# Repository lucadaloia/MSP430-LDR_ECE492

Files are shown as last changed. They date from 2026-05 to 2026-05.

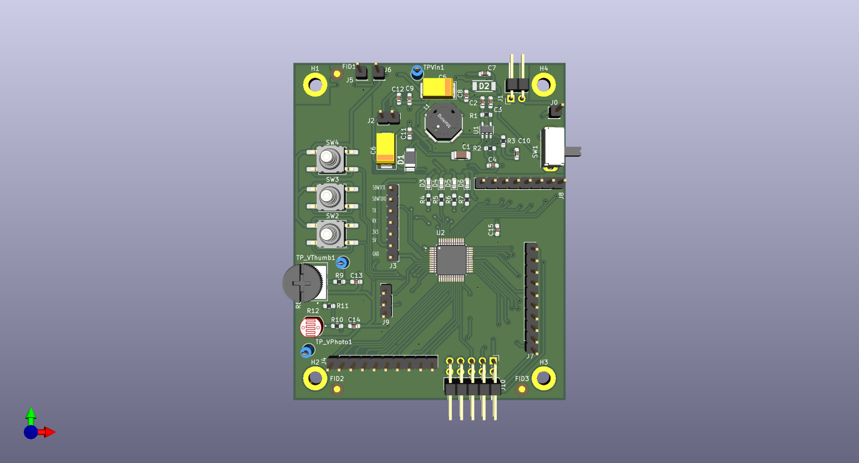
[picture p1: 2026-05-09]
Design Documents/ECE 492 - PCB 3D Render.png

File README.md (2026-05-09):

# MSP430-LDR_ECE492 
### ECE 492 (Embedded Systems Hardware Design) Project

## 📝 Overview
This project involved the design and manufacturing of a microcontroller-based system focused on analog signal acquisition and real-time user interaction. The system utilizes a photoresistor (LDR) for environmental sensing and a tactile user interface, all managed by a custom-designed PCB and optimized C firmware.

The core of the system is the **MSP430FR2355**, utilizing its 10-bit ADC12 module and hardware timers to create a responsive, low-power monitoring tool.

## 🛠 Hardware Specifications
- **MCU:** MSP430
- **Sensors:** Photoresistor (Analog A1) & Thumbwheel Potentiometer (Analog A2)
- **User Input:** 3x Tactile Pushbuttons (Hardware Interrupts)
- **Visual Output:** 4x LED Status Indicators (Blue, Yellow, Green, Red)

## 📂 Project Structure
- `main.c`: Central application logic and LED threshold management.
- `ADC.c`: 10-bit ADC12 configuration and sampling logic.
- `interrupts.c`: ISRs for Port 2 (Mode switching), Timer B (10Hz trigger), and ADC.
- `ports.c`: GPIO and Peripheral multiplexing setup.
- `timers.c`: Timer_B0 configuration using ACLK (~32.768 kHz).
- `globals.c`: Volatile variable definitions for shared system state.

## ⚙️ Technical Highlights
### 1. Automated ADC Chaining
To minimize CPU overhead, the firmware uses a "chaining" logic within the ADC Interrupt Service Routine. Once the photoresistor is sampled, the ISR automatically reconfigures the multiplexer to sample the thumbwheel, ensuring all sensor data is current without blocking the main loop.

### 2. Interrupt-Driven State Machine
The system switches between three operating modes via Port 2 interrupts:
- **Mode 1:** All-or-nothing binary threshold.
- **Mode 2:** Graduated response (LEDs light up sequentially based on intensity).
- **Mode 3:** Environmental calibration and baseline setting.

---
**Author:** Luca Daloia  
**Project Date:** Spring 2026  
**Course:** ECE 492

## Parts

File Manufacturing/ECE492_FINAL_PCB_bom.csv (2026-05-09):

Designator | Footprint | Quantity | Value | LCSC Part #
C1 | 1206 | 1 | 1.0UF
C10, C11, C12, C16, C17, C18, C19, C2, C20, C21, C22, C23, C24, C25, C7, C8, C9 | 0603 | 17 | 10UF
C13, C14, C15 | 0603 | 3 | 0.1uF
C3, C4 | 0603 | 2 | 470PF
C5 | CP_EIA-7132-20_AVX-U | 1 | 22UF
C6 | CP_EIA-7343-40_Kemet-Y | 1 | 100UF
D1, D2 | PMEG3020BEP,115 | 2 | PMEG3020BEP,115
D3 | 0603 | 1 | LTST-C190GKT
D4 | 0603 | 1 | LTST-C190KRKT
D5 | 0603 | 1 | LTST-C190KSKT
D6 | 0603 | 1 | LTST-C190TBKT
J0, J5, J6 | PinHeader_1x01_P2.54mm_Vertical | 3 | Conn_01x01
J1 | PinHeader_1x02_P2.54mm_Horizontal | 1 | Conn_01x02
J10 | PinHeader_2x05_P2.54mm_Horizontal | 1 | Conn_02x05_Odd_Even
J2 | PinHeader_1x02_P2.54mm_Vertical | 1 | Conn_01x02
J3 | PinHeader_1x07_P2.54mm_Vertical | 1 | Conn_01x07_Pin
J4, J7 | PinHeader_1x10_P2.54mm_Vertical | 2 | Conn_01x10_Pin
J8 | PinHeader_1x08_P2.54mm_Vertical | 1 | Conn_01x08_Pin
J9 | PinHeader_1x03_P2.54mm_Vertical | 1 | Conn_01x05_Pin
L1 | WE-TDC_8038 | 1 | WE-TDC_8038
R1 | 0603 | 1 | 10.0K
R10, R9 | 0603 | 2 | 1k
R11 | 0603 | 1 | 10k
R12 | PHODET_PDV-P8103 | 1 | PDV-P8103
R2 | 0603 | 1 | 12K
R3 | 0603 | 1 | 20K
R4, R5, R6, R7 | 0603 | 4 | 220
R8 | TRIM_3352T-1-103LF | 1 | 3352T-1-103LF
SW1 | SW_Slide_SPDT_Angled_CK_OS102011MA1Q | 1 | SW_SPDT
SW2, SW3, SW4 | SW_Push_1P1T_NO_CK_KSC9xxG | 3 | SW_DIP_x01
TPVIN1, TP_VPHOTO1, TP_VTHUMB1 | TestPoint_Loop_D1.80mm_Drill1.0mm_Beaded | 3 | TestPoint
U1 | LT1935ES5-TRPBF | 1 | LT1935ES5-TRPBF
U2 | MSP430FR2355TPT | 1 | MSP430FR2355TPT

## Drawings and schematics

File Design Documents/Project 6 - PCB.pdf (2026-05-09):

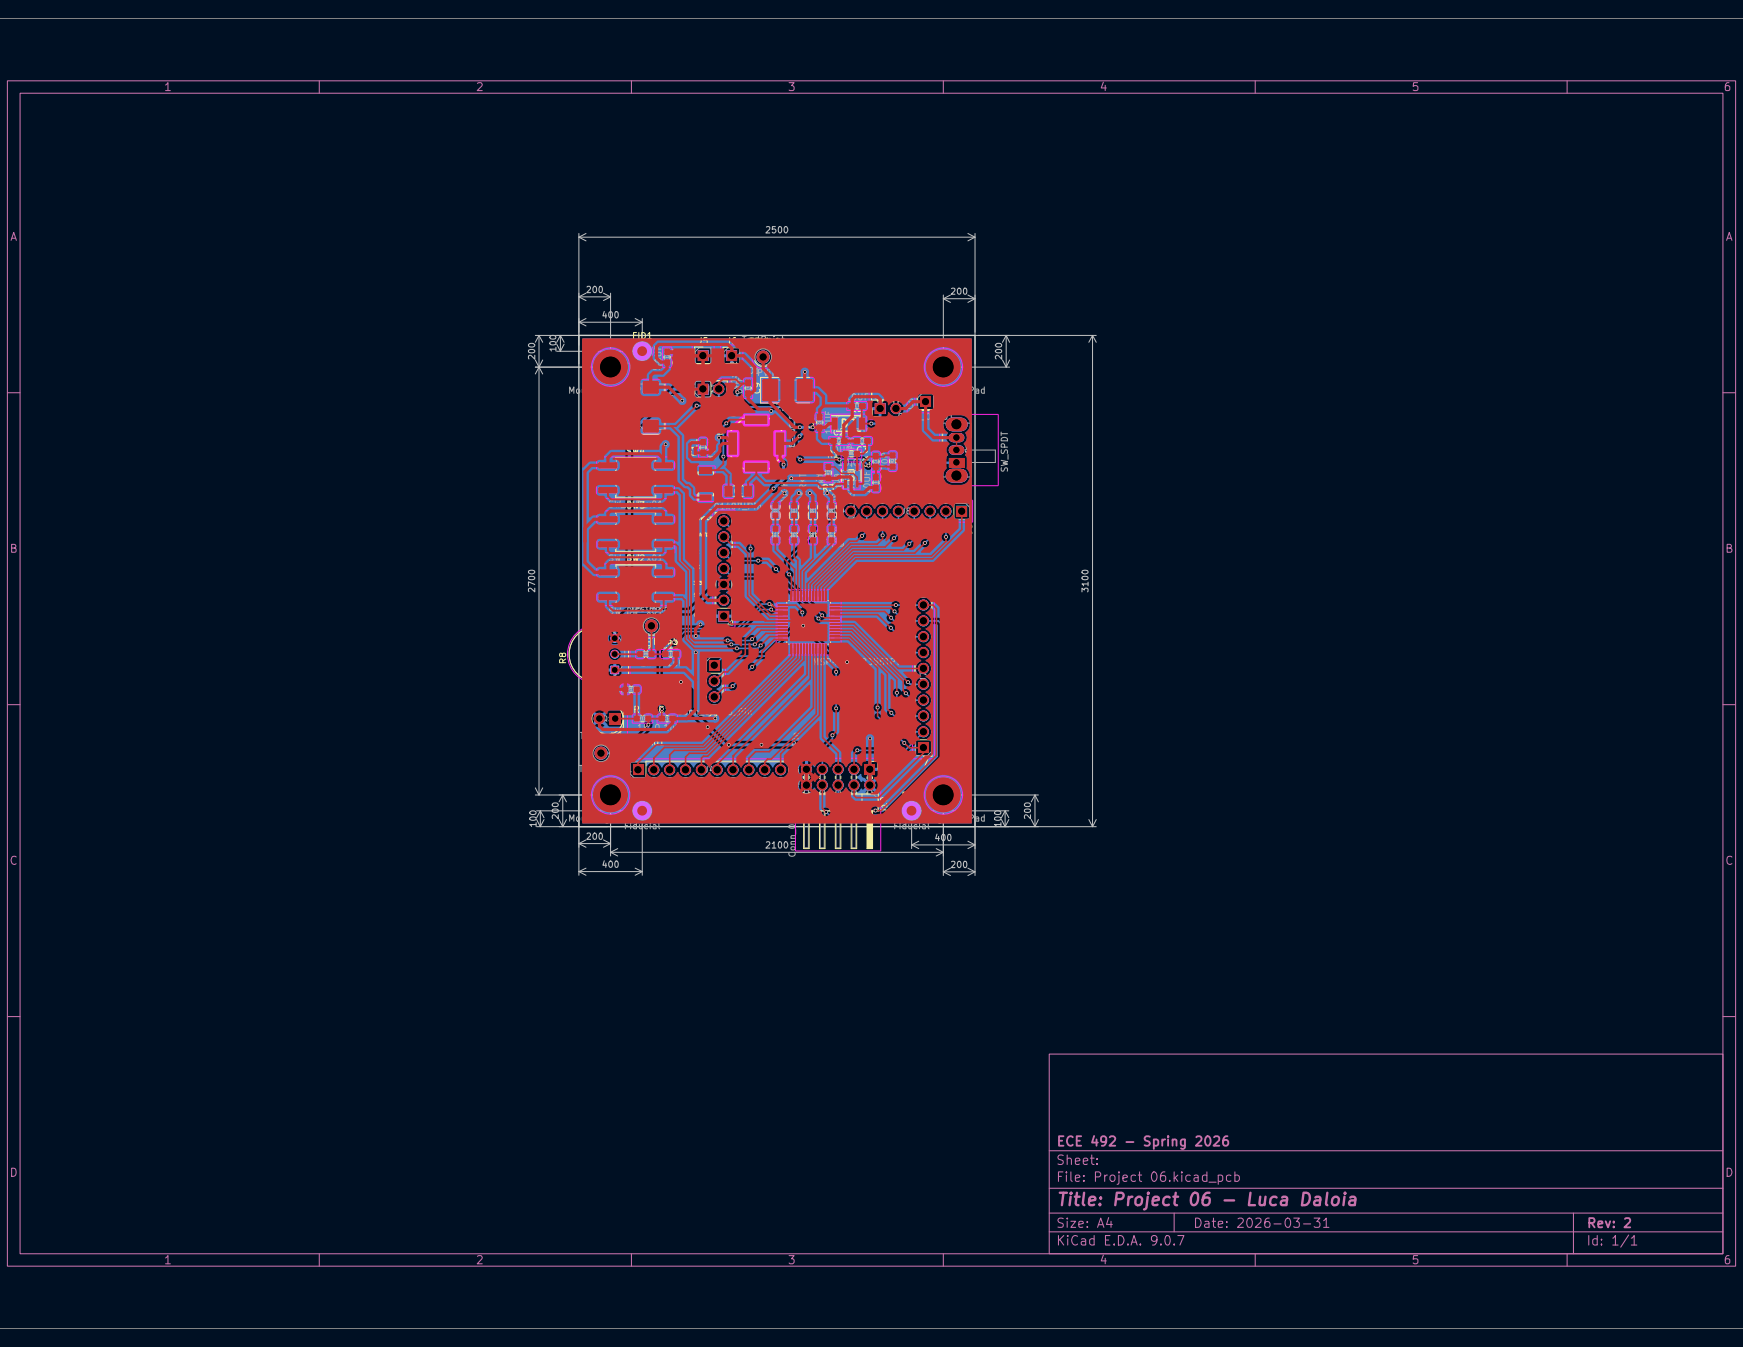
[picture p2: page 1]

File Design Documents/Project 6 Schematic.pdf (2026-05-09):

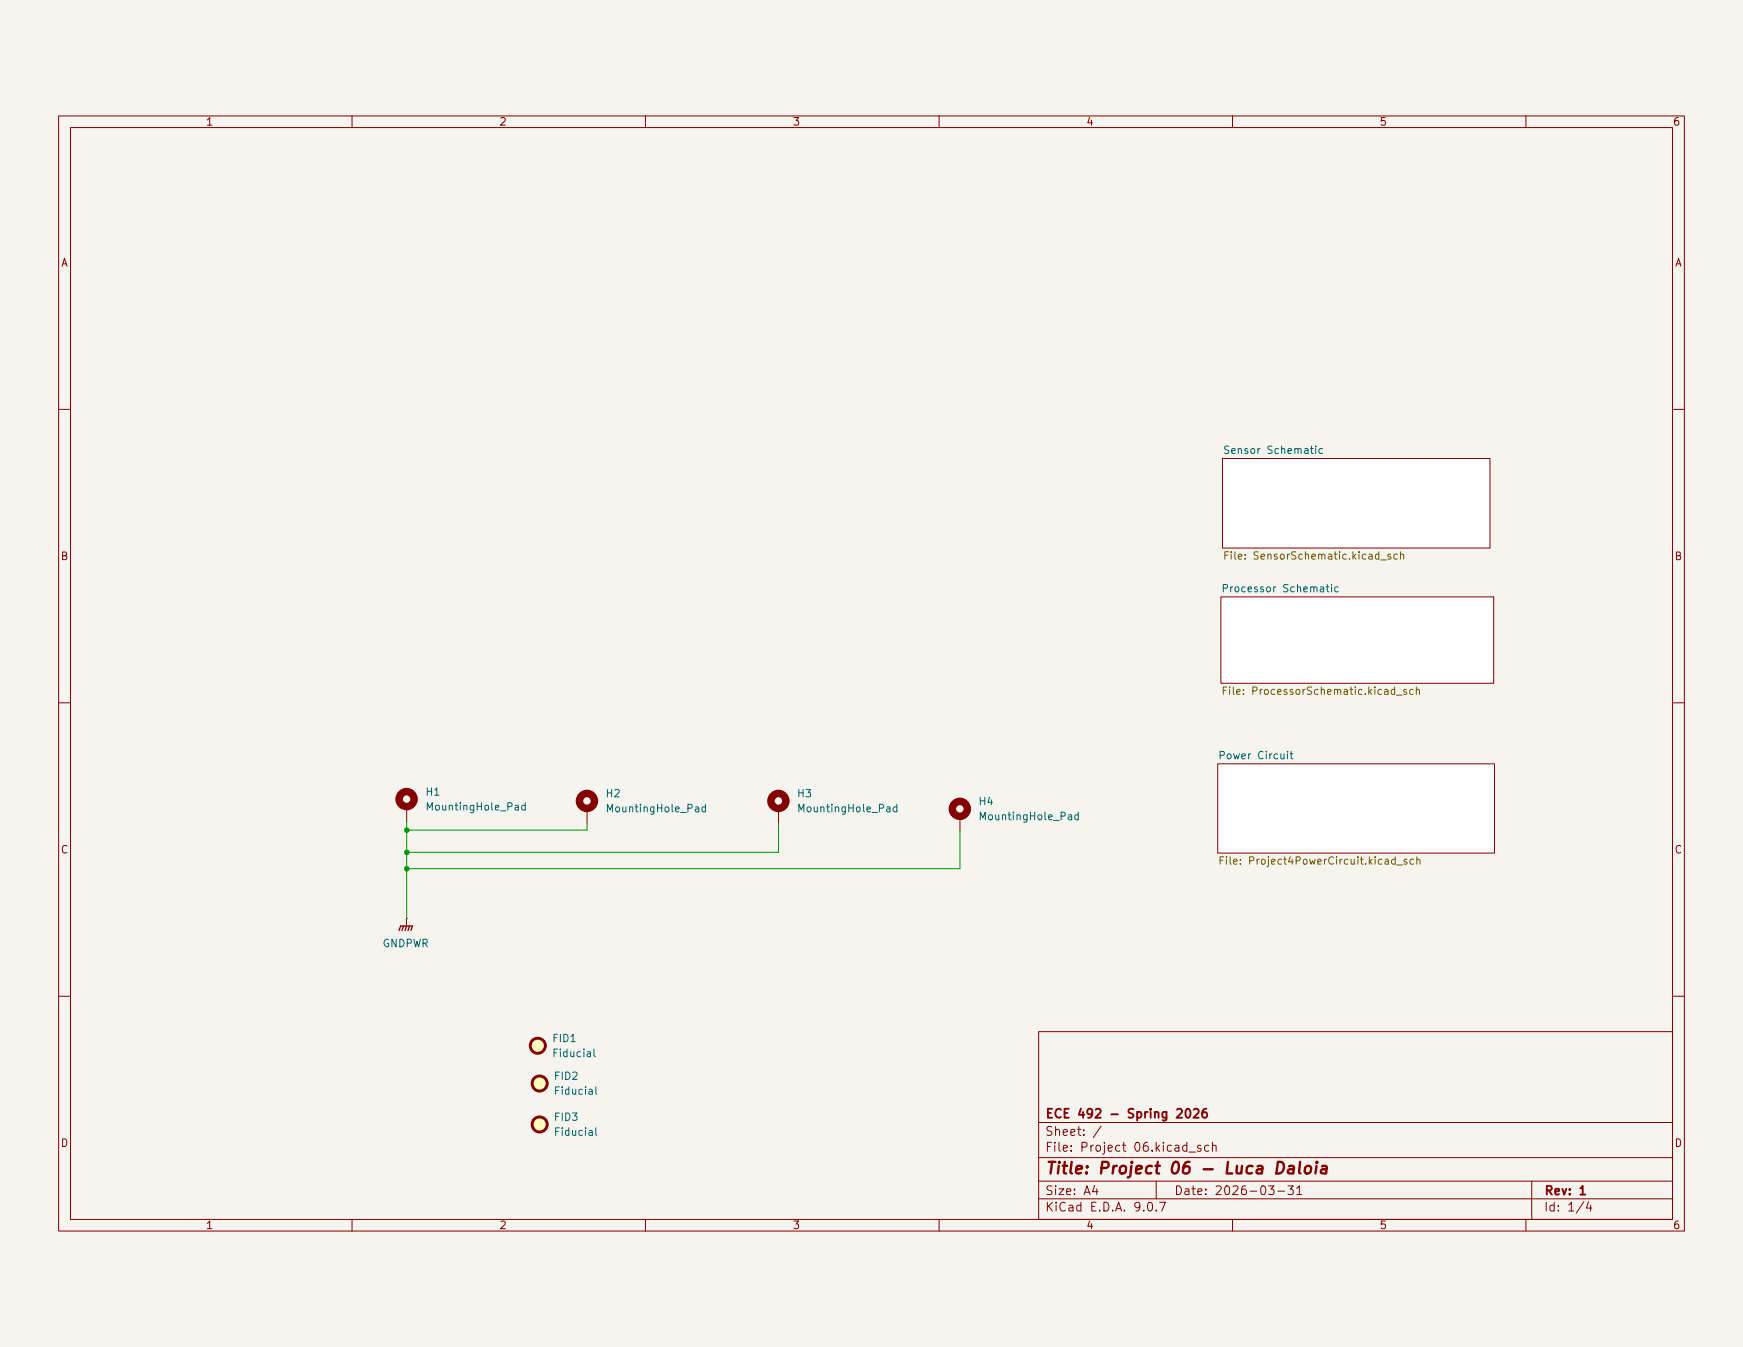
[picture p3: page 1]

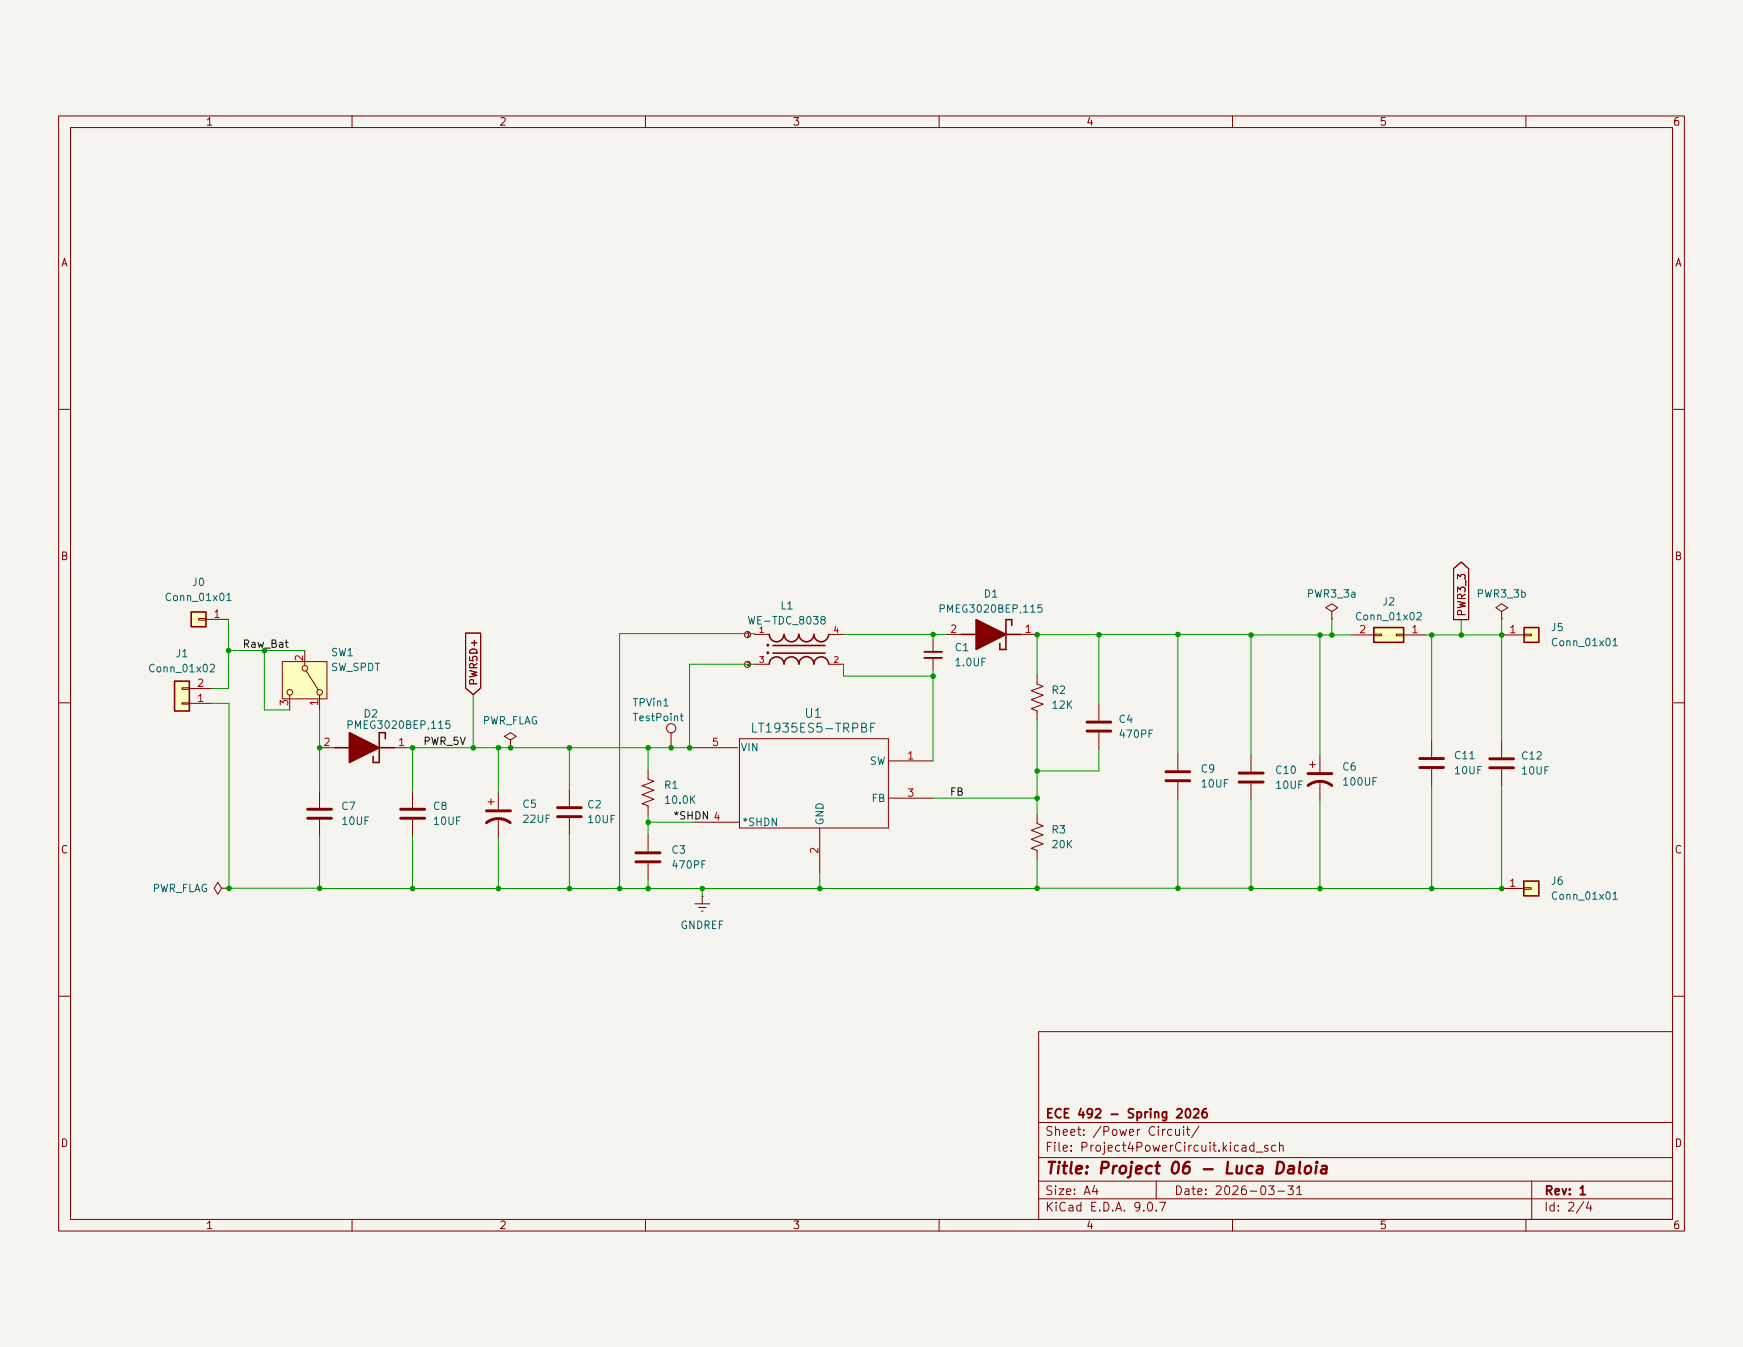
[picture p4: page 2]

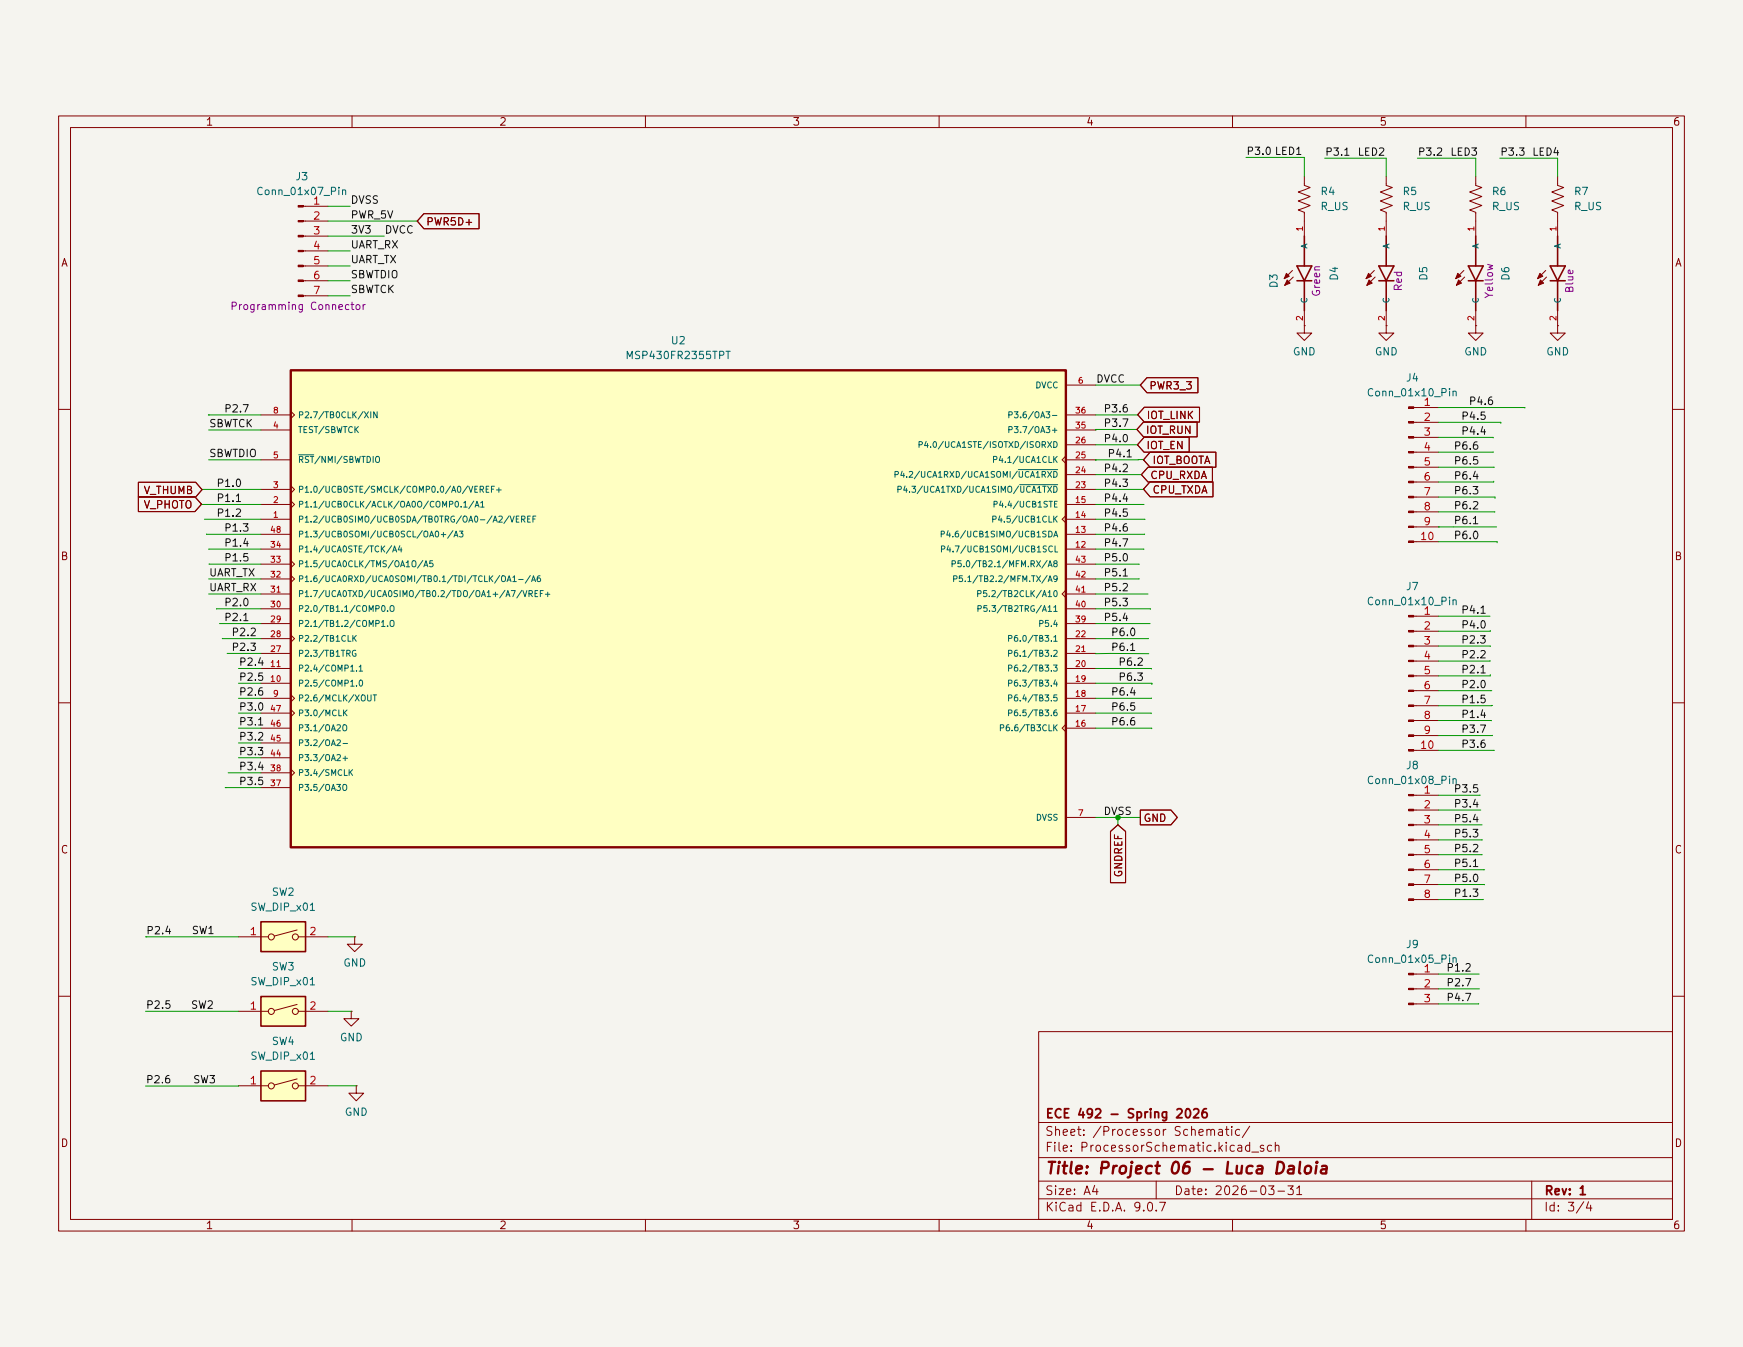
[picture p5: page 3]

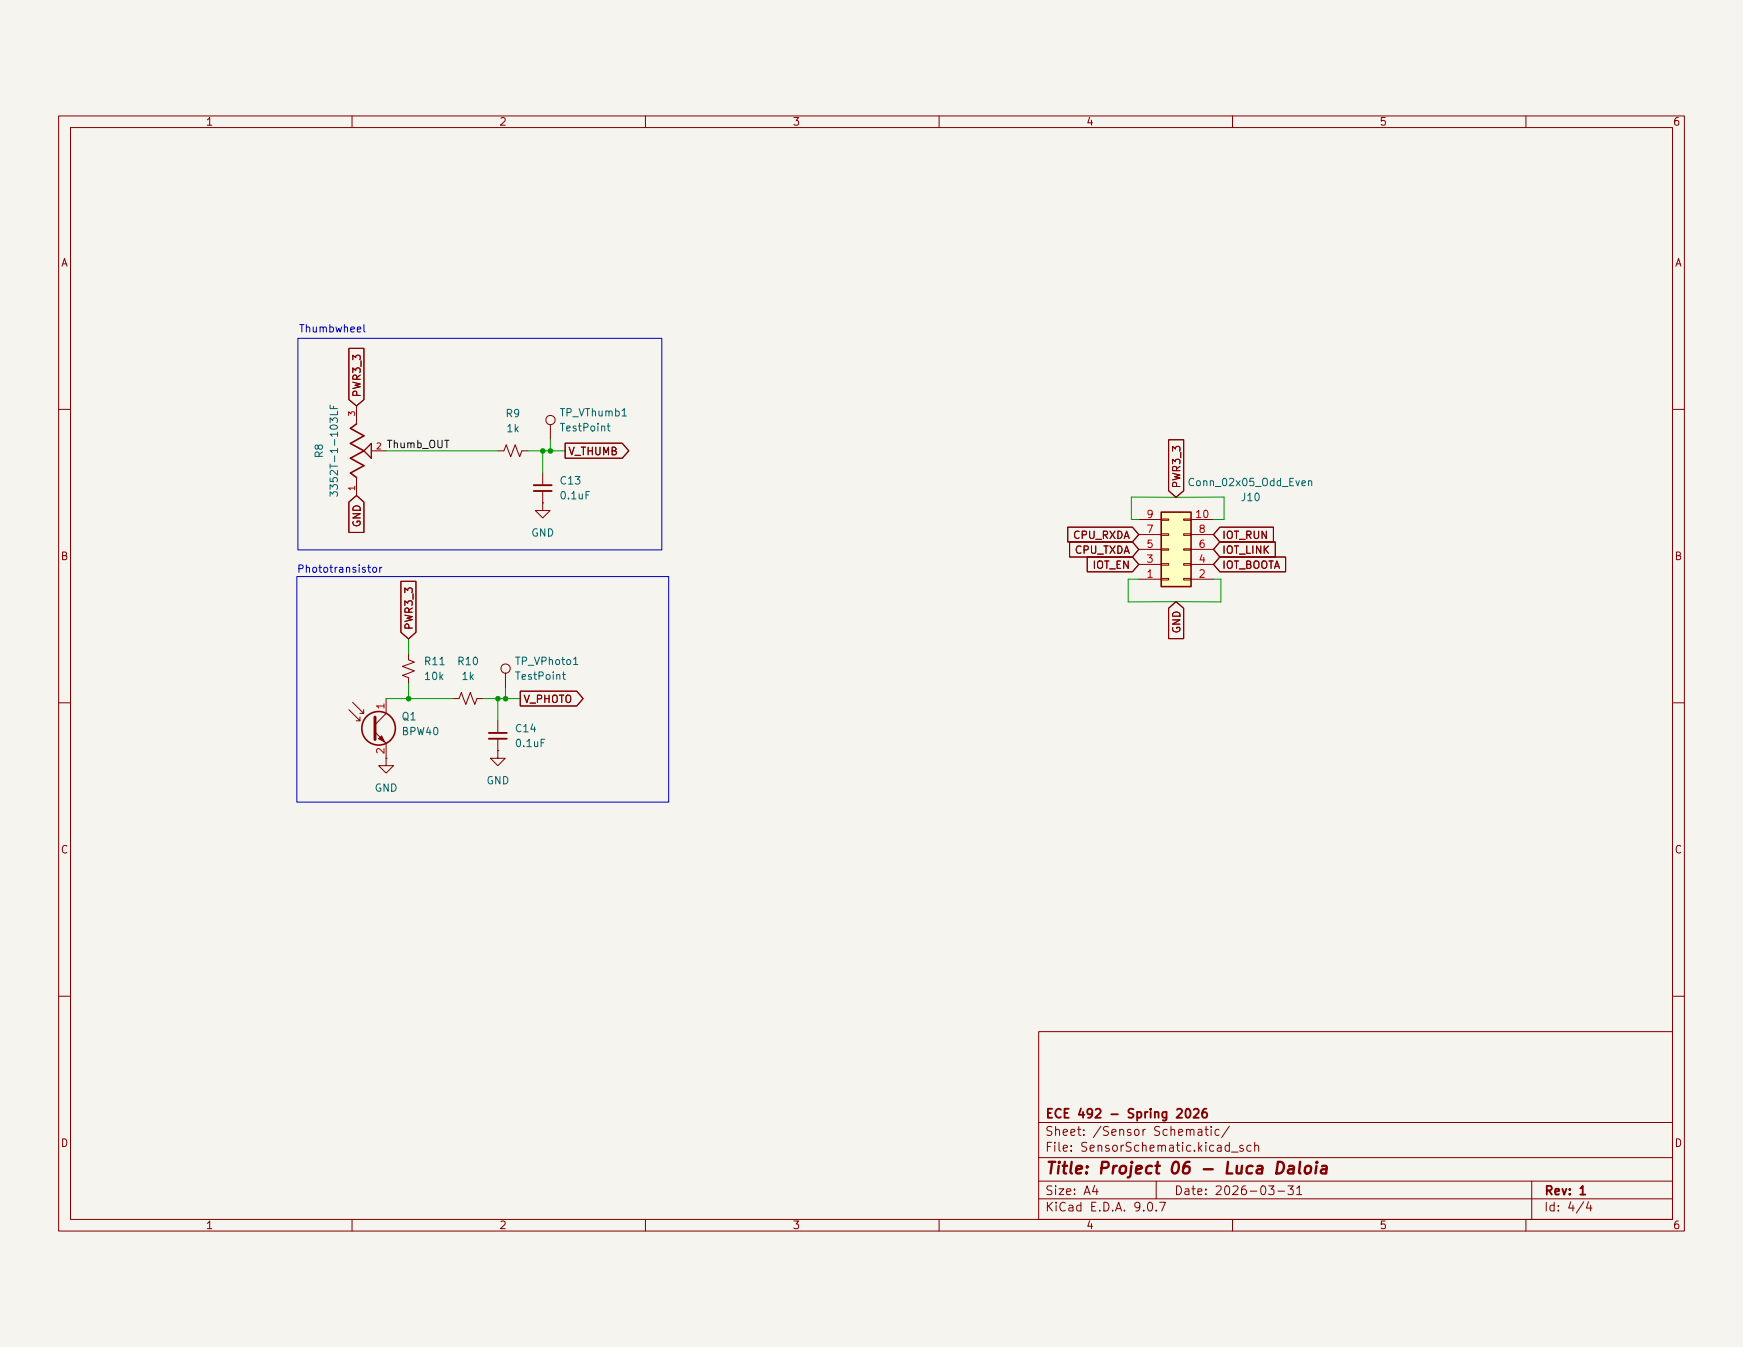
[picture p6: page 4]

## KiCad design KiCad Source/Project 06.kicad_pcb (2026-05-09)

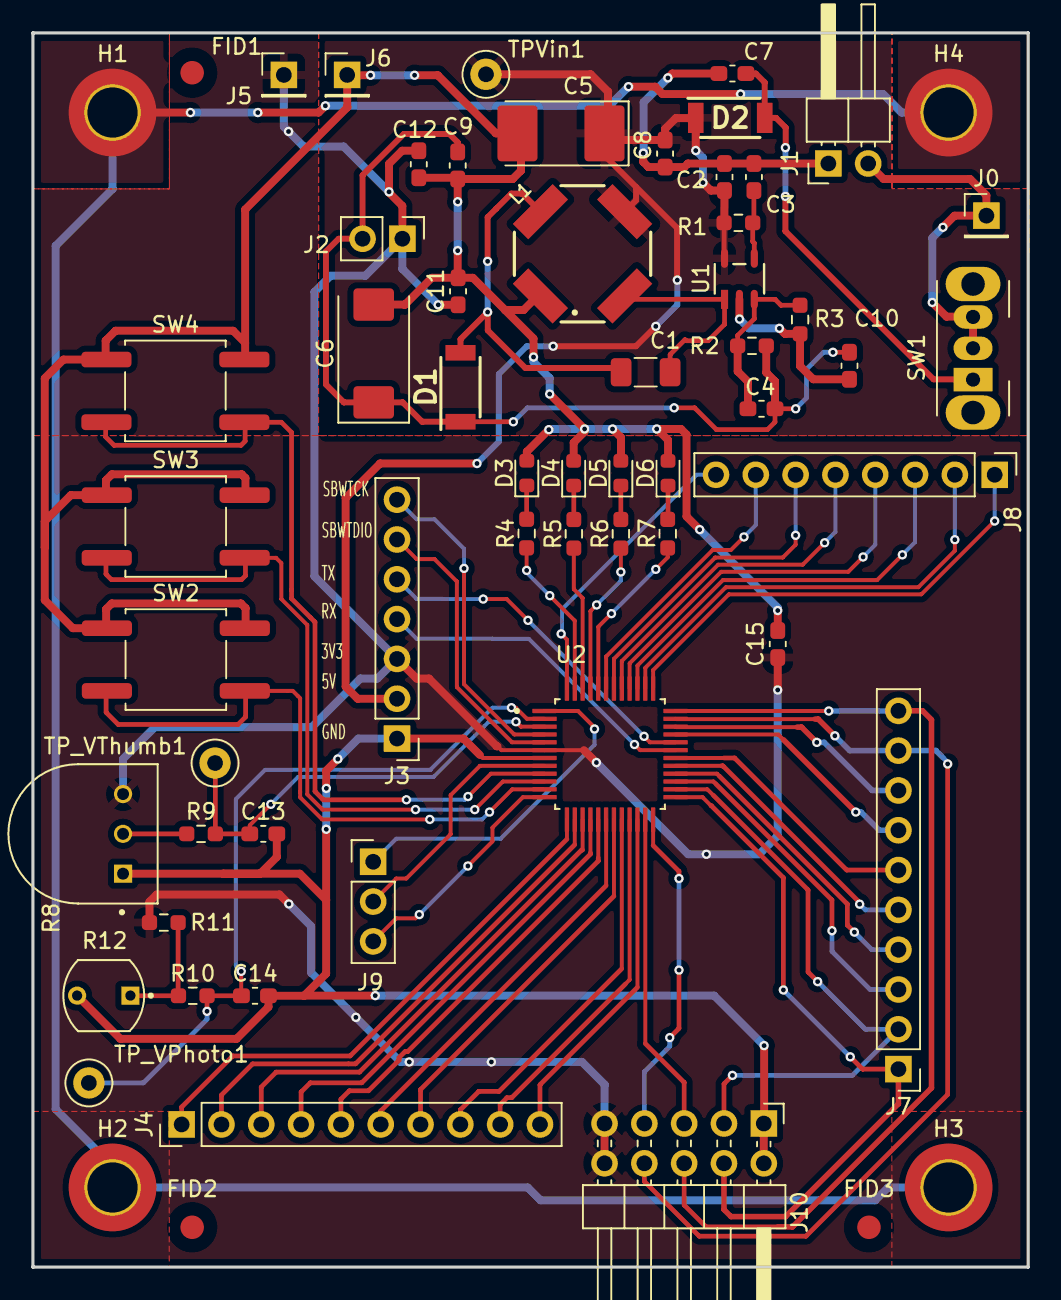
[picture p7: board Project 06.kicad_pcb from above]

Board: 2 copper layers, 63.5 x 78.7 mm, 61 parts (0 on the bottom side), 63 nets.

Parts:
C1: 1.0UF; C_1206_3216Metric_Pad1.33x1.80mm_HandSolder
C2, C7, C8, C9, C10, C11, C12: 10UF; C_0603_1608Metric_Pad1.08x0.95mm_HandSolder
C3, C4: 470PF; C_0603_1608Metric_Pad1.08x0.95mm_HandSolder
C5: 22UF; CP_EIA-7132-20_AVX-U
C6: 100UF; CP_EIA-7343-40_Kemet-Y
C13, C14: 0.1uF; C_0603_1608Metric_Pad1.08x0.95mm_HandSolder
C15: 0.1UF; C_0603_1608Metric_Pad1.08x0.95mm_HandSolder
D1, D2: PMEG3020BEP,115
D3: LTST-C190GKT; LED_0603_1608Metric
D4: LTST-C190KRKT; LED_0603_1608Metric
D5: LTST-C190KSKT; LED_0603_1608Metric
D6: LTST-C190TBKT; LED_0603_1608Metric
FID1, FID2, FID3: Fiducial; Fiducial_1.5mm_Mask3mm
H1, H2, H3, H4: MountingHole_Pad; MountingHole_3.2mm_M3_DIN965_Pad_TopOnly
J0, J5, J6: Conn_01x01; PinHeader_1x01_P2.54mm_Vertical
J1: Conn_01x02; PinHeader_1x02_P2.54mm_Horizontal
J2: Conn_01x02; PinHeader_1x02_P2.54mm_Vertical
J3: Conn_01x07_Pin; PinHeader_1x07_P2.54mm_Vertical
J4, J7: Conn_01x10_Pin; PinHeader_1x10_P2.54mm_Vertical
J8: Conn_01x08_Pin; PinHeader_1x08_P2.54mm_Vertical
J9: Conn_01x05_Pin; PinHeader_1x03_P2.54mm_Vertical
J10: Conn_02x05_Odd_Even; PinHeader_2x05_P2.54mm_Horizontal
L1: WE-TDC_8038
R1: 10.0K; R_0603_1608Metric_Pad0.98x0.95mm_HandSolder
R2: 12K; R_0603_1608Metric_Pad0.98x0.95mm_HandSolder
R3: 20K; R_0603_1608Metric_Pad0.98x0.95mm_HandSolder
R4, R5, R6, R7: 220; R_0603_1608Metric_Pad0.98x0.95mm_HandSolder
R8: 3352T-1-103LF; TRIM_3352T-1-103LF
R9, R10: 1k; R_0603_1608Metric_Pad0.98x0.95mm_HandSolder
R11: 10k; R_0603_1608Metric_Pad0.98x0.95mm_HandSolder
R12: PDV-P8103; PHODET_PDV-P8103
SW1: SW_SPDT; SW_Slide_SPDT_Angled_CK_OS102011MA1Q
SW2, SW3, SW4: SW_DIP_x01; SW_Push_1P1T_NO_CK_KSC9xxG
TPVin1: TestPoint; TestPoint_Loop_D1.80mm_Drill1.0mm_Beaded
TP_VPhoto1: TestPoint; TestPoint_Loop_D1.80mm_Drill1.0mm_Beaded
TP_VThumb1: TestPoint; TestPoint_Loop_D1.80mm_Drill1.0mm_Beaded
U1: LT1935ES5-TRPBF
U2: MSP430FR2355TPT

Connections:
/Power Circuit/*SHDN: C3.1, R1.2, U1.4 (*SHDN)
/Power Circuit/FB: C4.2, R2.2, R3.1, U1.3 (FB)
/Power Circuit/Raw_Bat: J0.1, J1.2, SW1.2 (B), SW1.3 (C)
/Processor Schematic/LED1: R4.1, U2.47 (P3.0/MCLK)
/Processor Schematic/LED2: R5.1, U2.46 (P3.1/OA2O)
/Processor Schematic/LED3: R6.1, U2.45 (P3.2/OA2-)
/Processor Schematic/LED4: R7.1, U2.44 (P3.3/OA2+)
/Processor Schematic/P1.2: J9.1, U2.1 (P1.2/UCB0SIMO/UCB0SDA/TB0TRG/OA0-/A2/VE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)
/Processor Schematic/P1.3: J8.8, U2.48 (P1.3/UCB0SOMI/UCB0SCL/OA0+/A3)
/Processor Schematic/P1.4: J7.8, U2.34 (P1.4/UCA0STE/TCK/A4)
/Processor Schematic/P1.5: J7.7, U2.33 (P1.5/UCA0CLK/TMS/OA1O/A5)
/Processor Schematic/P2.0: J7.6, U2.30 (P2.0/TB1.1/COMP0.O)
/Processor Schematic/P2.1: J7.5, U2.29 (P2.1/TB1.2/COMP1.O)
/Processor Schematic/P2.2: J7.4, U2.28 (P2.2/TB1CLK)
/Processor Schematic/P2.3: J7.3, U2.27 (P2.3/TB1TRG)
/Processor Schematic/P2.4: SW2.1, U2.11 (P2.4/COMP1.1)
/Processor Schematic/P2.5: SW3.1, U2.10 (P2.5/COMP1.0)
/Processor Schematic/P2.6: SW4.1, U2.9 (P2.6/MCLK/XOUT)
/Processor Schematic/P2.7: J9.2, U2.8 (P2.7/TB0CLK/XIN)
/Processor Schematic/P3.4: J8.2, U2.38 (P3.4/SMCLK)
/Processor Schematic/P3.5: J8.1, U2.37 (P3.5/OA3O)
/Processor Schematic/P4.4: J4.3, U2.15 (P4.4/UCB1STE)
/Processor Schematic/P4.5: J4.2, U2.14 (P4.5/UCB1CLK)
/Processor Schematic/P4.6: J4.1, U2.13 (P4.6/UCB1SIMO/UCB1SDA)
/Processor Schematic/P4.7: J9.3, U2.12 (P4.7/UCB1SOMI/UCB1SCL)
/Processor Schematic/P5.0: J8.7, U2.43 (P5.0/TB2.1/MFM.RX/A8)
/Processor Schematic/P5.1: J8.6, U2.42 (P5.1/TB2.2/MFM.TX/A9)
/Processor Schematic/P5.2: J8.5, U2.41 (P5.2/TB2CLK/A10)
/Processor Schematic/P5.3: J8.4, U2.40 (P5.3/TB2TRG/A11)
/Processor Schematic/P5.4: J8.3, U2.39 (P5.4)
/Processor Schematic/P6.0: J4.10, U2.22 (P6.0/TB3.1)
/Processor Schematic/P6.1: J4.9, U2.21 (P6.1/TB3.2)
/Processor Schematic/P6.2: J4.8, U2.20 (P6.2/TB3.3)
/Processor Schematic/P6.3: J4.7, U2.19 (P6.3/TB3.4)
/Processor Schematic/P6.4: J4.6, U2.18 (P6.4/TB3.5)
/Processor Schematic/P6.5: J4.5, U2.17 (P6.5/TB3.6)
/Processor Schematic/P6.6: J4.4, U2.16 (P6.6/TB3CLK)
/Processor Schematic/SBWTCK: J3.7, U2.4 (TEST/SBWTCK)
/Processor Schematic/SBWTDIO: J3.6, U2.5 (~RST/NMI/SBWTDIO)
/Processor Schematic/UART_RX: J3.4, U2.31 (P1.7/UCA0TXD/UCA0SIMO/TB0.2/TDO/OA1+/A7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)
/Processor Schematic/UART_TX: J3.5, U2.32 (P1.6/UCA0RXD/UCA0SOMI/TB0.1/TDI/TCLK/OA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)
/Sensor Schematic/Thumb_OUT: R8.2, R9.1
CPU_RXDA: J10.7 (Pin_3), U2.24 (P4.2/UCA1RXD/UCA1SOMI/~UCA1RXD)
CPU_TXDA: J10.5, U2.23 (P4.3/UCA1TXD/UCA1SIMO/~UCA1TXD)
GND: C2.2, C3.2, C5.2, C6.2, C7.2, C8.2, C9.2, C10.2, C11.2, C12.2, C13.2, C14.2, C15.2, D3.2 (C), D4.2 (C), D5.2 (C), D6.2 (C), J1.1, J3.1, J6.1, J10.1 (Pin_9), J10.2 (Pin_10), L1.1, R3.2, R8.1, R12.2, SW2.2, SW3.2, SW4.2, U1.2 (GND), U2.7 (DVSS)
GNDPWR: H1.1, H2.1, H3.1, H4.1
IOT_BOOTA: J7.1, J10.4 (Pin_8), U2.25 (P4.1/UCA1CLK)
IOT_EN: J7.2, J10.3 (Pin_7), U2.26 (P4.0/UCA1STE/ISOTXD/ISORXD)
IOT_LINK: J7.10, J10.6, U2.36 (P3.6/OA3-)
IOT_RUN: J7.9, J10.8 (Pin_4), U2.35 (P3.7/OA3+)
unnamed: C1.1, D1.2 (A), L1.4
unnamed: C4.1, C6.1, C9.1, C10.1, D1.1 (K), J2.2, R2.1
unnamed: C7.1, D2.2 (A), SW1.1 (A)
unnamed: D3.1 (A), R4.2
unnamed: D4.1 (A), R5.2
unnamed: D5.1 (A), R6.2
unnamed: D6.1 (A), R7.2
unnamed: R10.1, R11.1, R12.1
unnamed: C1.2, L1.2, U1.1 (SW)
PWR3_3: C11.1, C12.1, C15.1, J2.1, J3.3, J5.1, J10.9 (Pin_1), J10.10 (Pin_2), R8.3, R11.2, U2.6 (DVCC)
PWR5D+: C2.1, C5.1, C8.1, D2.1 (K), J3.2, L1.3, R1.1, TPVin1.1, U1.5 (VIN)
V_PHOTO: C14.1, R10.2, TP_VPhoto1.1, U2.2 (P1.1/UCB0CLK/ACLK/OA0O/COMP0.1/A1)
V_THUMB: C13.1, R9.2, TP_VThumb1.1, U2.3 (P1.0/UCB0STE/SMCLK/COMP0.0/A0/VEREF+)

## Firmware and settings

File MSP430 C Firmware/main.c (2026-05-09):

/*******************************************************************************
 * @file        main.c
 * @brief       Main application entry point and system control logic.
 * @project     MSP430 Sensor Suite
 * @author      Luca
 * @date        May 5, 2026
 * * @description
 * This file serves as the central hub of the application. It initializes
 * hardware peripherals, manages the global state machine (modes 1-3), and
 * controls the LED output logic based on photoresistor thresholds.
 ******************************************************************************/

#include "ProjectMaster.h"

int main(void) {
    // Stop the watchdog timer to prevent constant resets
    WDTCTL = WDTPW | WDTHOLD;

    Init_Ports();
    Init_Timer();
    Init_ADC();



    P3OUT |= RED_LED;   //Turn LED on to display power



    // Disable the GPIO power-on default high-impedance mode
    // This is required for FR series (FRAM) MSP430s to activate the settings
    PM5CTL0 &= ~LOCKLPM5;
    __enable_interrupt();
    // Infinite loop to keep the LEDs illuminated
    while(1) {
        switch (mode){
        case 1:
            if (photo_val > (initial_photo_val + 60)){
                P3OUT |= BLUE_LED;
                P3OUT |= YELLOW_LED;
                P3OUT |= GREEN_LED;
            }
            else {
                P3OUT &= ~BLUE_LED;
                P3OUT &= ~YELLOW_LED;
                P3OUT &= ~GREEN_LED;
            }
            break;
        case 2:
            if (photo_val > (initial_photo_val + 60)){
                P3OUT |= GREEN_LED;
            }
            else P3OUT &= ~GREEN_LED;
            if (photo_val > (initial_photo_val + 80)){
                P3OUT |= YELLOW_LED;
            }
            else P3OUT &= ~YELLOW_LED;
            if (photo_val > (initial_photo_val + 100)){
                P3OUT |= BLUE_LED;
            }
            else P3OUT &= ~BLUE_LED;
            break;
        case 3:
            P3OUT &= ~BLUE_LED;
            P3OUT &= ~YELLOW_LED;
            P3OUT &= ~GREEN_LED;
            break;
        default: break;
        }

        __no_operation();
    }

    return 0;
}

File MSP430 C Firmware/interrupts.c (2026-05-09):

/*******************************************************************************
 * @file        interrupts.c
 * @brief       Global Interrupt Service Routines (ISRs).
 * @project     MSP430 Sensor Suite
 * @author      Luca
 * @date        May 5, 2026
 * * @description
 * Handles critical asynchronous events including:
 * - Port 2: Button debouncing and mode switching.
 * - Timer B0: 10Hz trigger for ADC conversions.
 * - ADC: Automated channel switching logic between the Photoresistor (A1)
 * and Thumbwheel (A2).
 ******************************************************************************/

#include "ProjectMaster.h"

#pragma vector=PORT2_VECTOR
__interrupt void Port_2_ISR(void){
        // SW1 (P2.4) ISR
        if (P2IFG & SW1) {
            // Perform action
            mode = 1;
            P2IFG &= ~SW1;                                // CLEAR THE FLAG
        }

        // SW2 (P2.5) ISR
        if (P2IFG & SW2) {
            //perform action
            mode = 2;
            P2IFG &= ~SW2;                                 // CLEAR THE FLAG
        }

        // SW3 (P2.6) ISR
        if (P2IFG & SW3) {
            //perform action
            mode = 3;
            initial_photo_val = photo_val;
            P2IFG &= ~SW3;                                 // CLEAR THE FLAG
        }
}



//------------------------------------------------------------------------------
// Timer B0 CCR0 Interrupt Service Routine
// Triggers the ADC conversion every timer cycle (approx 10Hz)
//------------------------------------------------------------------------------
#pragma vector = TIMER0_B0_VECTOR
__interrupt void Timer_B_ISR(void) {
    // Start the first conversion in the chain (Photoresistor)
    ADCCTL0 |= ADCSC;
}

//------------------------------------------------------------------------------
// ADC Interrupt Service Routine
// Fires when a conversion is complete
//------------------------------------------------------------------------------
#pragma vector = ADC_VECTOR
__interrupt void ADC_ISR(void) {
    switch(__even_in_range(ADCIV, ADCIV_ADCIFG)) {
        case ADCIV_ADCIFG:

            ADCCTL0 &= ~ADCENC;

            switch (ADC_Channel) {
                case 0: // Just finished A1 (Photoresistor)
                    photo_val = ADCMEM0 / 4;

                    // 2. DISABLE current channel (A1)
                    ADCMCTL0 &= ~ADCINCH_1;
                    // 3. ENABLE next channel (A2)
                    ADCMCTL0 |= ADCINCH_2;

                    ADC_Channel = 1;

                    // 4. Start the next conversion
                    ADCCTL0 |= ADCENC | ADCSC;
                    break;

                case 1: // Just finished A2 (Thumbwheel)
                    thumb_val = ADCMEM0 / 4;

                    // 5. DISABLE current channel (A2)
                    ADCMCTL0 &= ~ADCINCH_2;
                    // 6. ENABLE next channel (A1)
                    ADCMCTL0 |= ADCINCH_1;

                    ADC_Channel = 0;

                    // 7. Re-enable but WAIT for the Timer
                    ADCCTL0 |= ADCENC;
                    break;
            }
            break;
    }
}
